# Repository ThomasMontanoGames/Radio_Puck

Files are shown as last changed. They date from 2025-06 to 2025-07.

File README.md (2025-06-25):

# Radio_Puck
Small STM32 based ethernet connected radio puck capable of full duplex transmit and receive as well as dual RX or dual TX. Capable of rates up to 1 Mbps and completely configurable for many kinds of different modes. This radio puck has been primarily designed to be your rubber duck that transmits a known signal while prototyping a receiver.

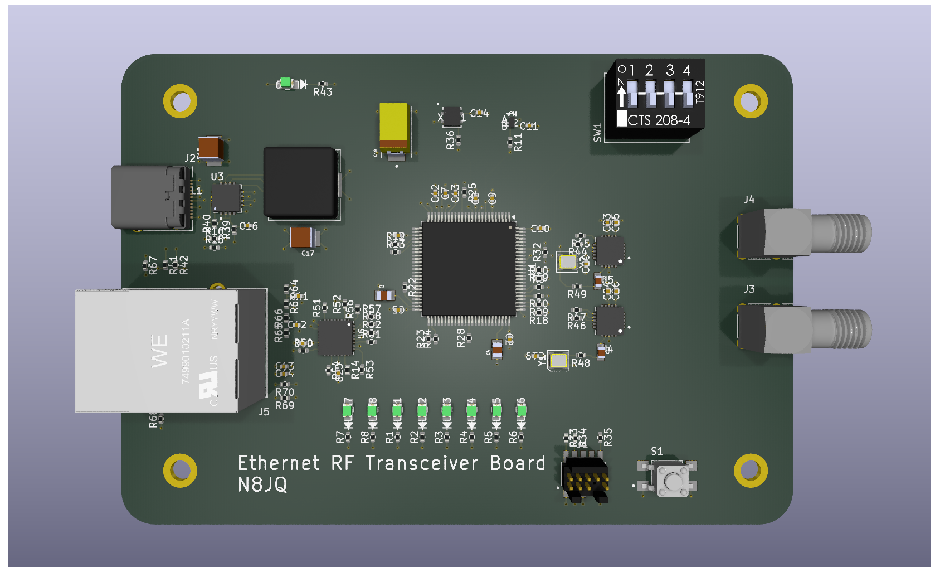
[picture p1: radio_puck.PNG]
Preliminary Layout


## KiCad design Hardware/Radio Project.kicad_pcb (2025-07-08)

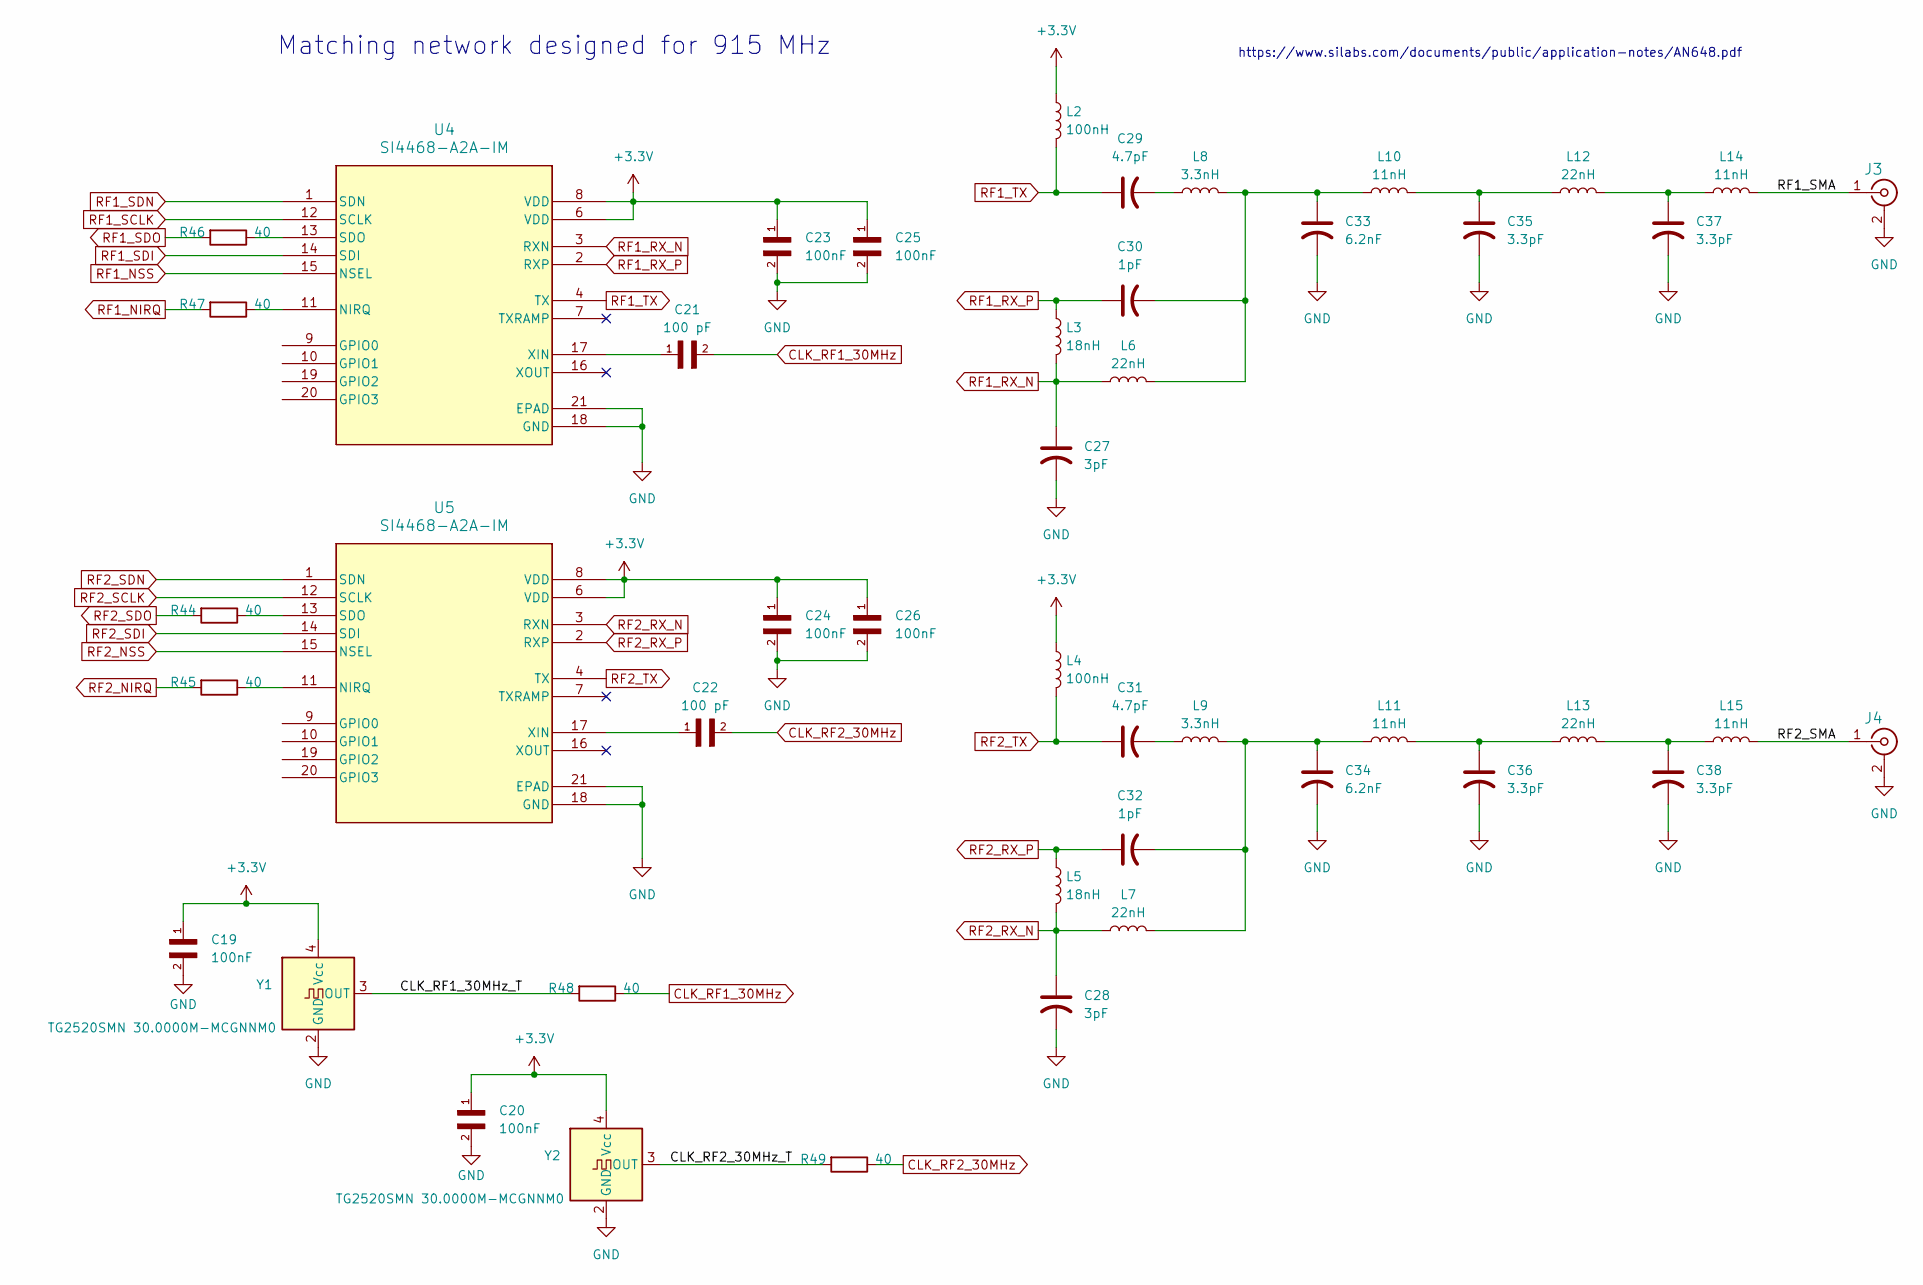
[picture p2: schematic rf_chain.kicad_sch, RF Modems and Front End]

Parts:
C19, C20, C23, C24, C25, C26: 100nF; CAPC10555_55N_KEM-L
C21, C22: 100 pF; CAPC1608X90N
C27, C28: 3pF; C_01005_0402Metric
C29, C31: 4.7pF; C_01005_0402Metric
C30, C32: 1pF; C_01005_0402Metric
C33, C34: 6.2nF; C_01005_0402Metric
C35, C36, C37, C38: 3.3pF; C_01005_0402Metric
J3, J4: 132225; CONN_132225_AMP
L2, L4: 100nH; L_0402_1005Metric
L3, L5: 18nH; L_0402_1005Metric
L6, L7, L12, L13: 22nH; L_0402_1005Metric
L8, L9: 3.3nH; L_0402_1005Metric
L10, L11, L14, L15: 11nH; L_0402_1005Metric
R44, R45, R46, R47, R48, R49: 40; R_0402_1005Metric
U4, U5: SI4468-A2A-IM; QFN50P400X400X90-21N
Y1, Y2: TG2520SMN 30.0000M-MCGNNM0; TG2520SMN

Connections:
+3.3V: C19.1, C20.1, C23.1, C24.1, C25.1, C26.1, L2.1, L4.1, U4.6 (VDD), U4.8 (VDD), U5.6 (VDD), U5.8 (VDD), Y1.4 (Vcc), Y2.4 (Vcc); also elsewhere on the board
/RF Chain/CLK_RF1_30MHz_T: R48.2, Y1.3 (OUT)
/RF Chain/CLK_RF2_30MHz_T: R49.2, Y2.3 (OUT)
/RF Chain/RF1_SMA: J3.1, L14.2
/RF Chain/RF2_SMA: J4.1, L15.2
CLK_RF1_30MHz: C21.2, R48.1
CLK_RF2_30MHz: C22.2, R49.1
GND: C19.2, C20.2, C23.2, C24.2, C25.2, C26.2, C27.2, C28.2, C33.2, C34.2, C35.2, C36.2, C37.2, C38.2, J3.2, J4.2, U4.18 (GND), U4.21 (EPAD), U5.18 (GND), U5.21 (EPAD), Y1.2 (GND), Y2.2 (GND); also elsewhere on the board
unnamed: C29.2, L8.1
unnamed: C30.2, C33.1, L6.2, L8.2, L10.1
unnamed: C31.2, L9.1
unnamed: C32.2, C34.1, L7.2, L9.2, L11.1
unnamed: C35.1, L10.2, L12.1
unnamed: C36.1, L11.2, L13.1
unnamed: C37.1, L12.2, L14.1
unnamed: C38.1, L13.2, L15.1
unnamed: R47.1, U4.11 (NIRQ)
unnamed: R46.1, U4.13 (SDO)
unnamed: C21.1, U4.17 (XIN)
unnamed: R45.1, U5.11 (NIRQ)
unnamed: R44.1, U5.13 (SDO)
unnamed: C22.1, U5.17 (XIN)
RF1_NIRQ: R47.2; also elsewhere on the board
RF1_NSS: U4.15 (NSEL); also elsewhere on the board
RF1_RX_N: C27.1, L3.2, L6.1, U4.3 (RXN)
RF1_RX_P: C30.1, L3.1, U4.2 (RXP)
RF1_SCLK: U4.12 (SCLK); also elsewhere on the board
RF1_SDI: U4.14 (SDI); also elsewhere on the board
RF1_SDN: U4.1 (SDN); also elsewhere on the board
RF1_SDO: R46.2; also elsewhere on the board
RF1_TX: C29.1, L2.2, U4.4 (TX)
RF2_NIRQ: R45.2; also elsewhere on the board
RF2_NSS: U5.15 (NSEL); also elsewhere on the board
RF2_RX_N: C28.1, L5.2, L7.1, U5.3 (RXN)
RF2_RX_P: C32.1, L5.1, U5.2 (RXP)
RF2_SCLK: U5.12 (SCLK); also elsewhere on the board
RF2_SDI: U5.14 (SDI); also elsewhere on the board
RF2_SDN: U5.1 (SDN); also elsewhere on the board
RF2_SDO: R44.2; also elsewhere on the board
RF2_TX: C31.1, L4.2, U5.4 (TX)

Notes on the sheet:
https://www.silabs.com/documents/public/application-notes/AN648.pdf
Matching network designed for 915 MHz

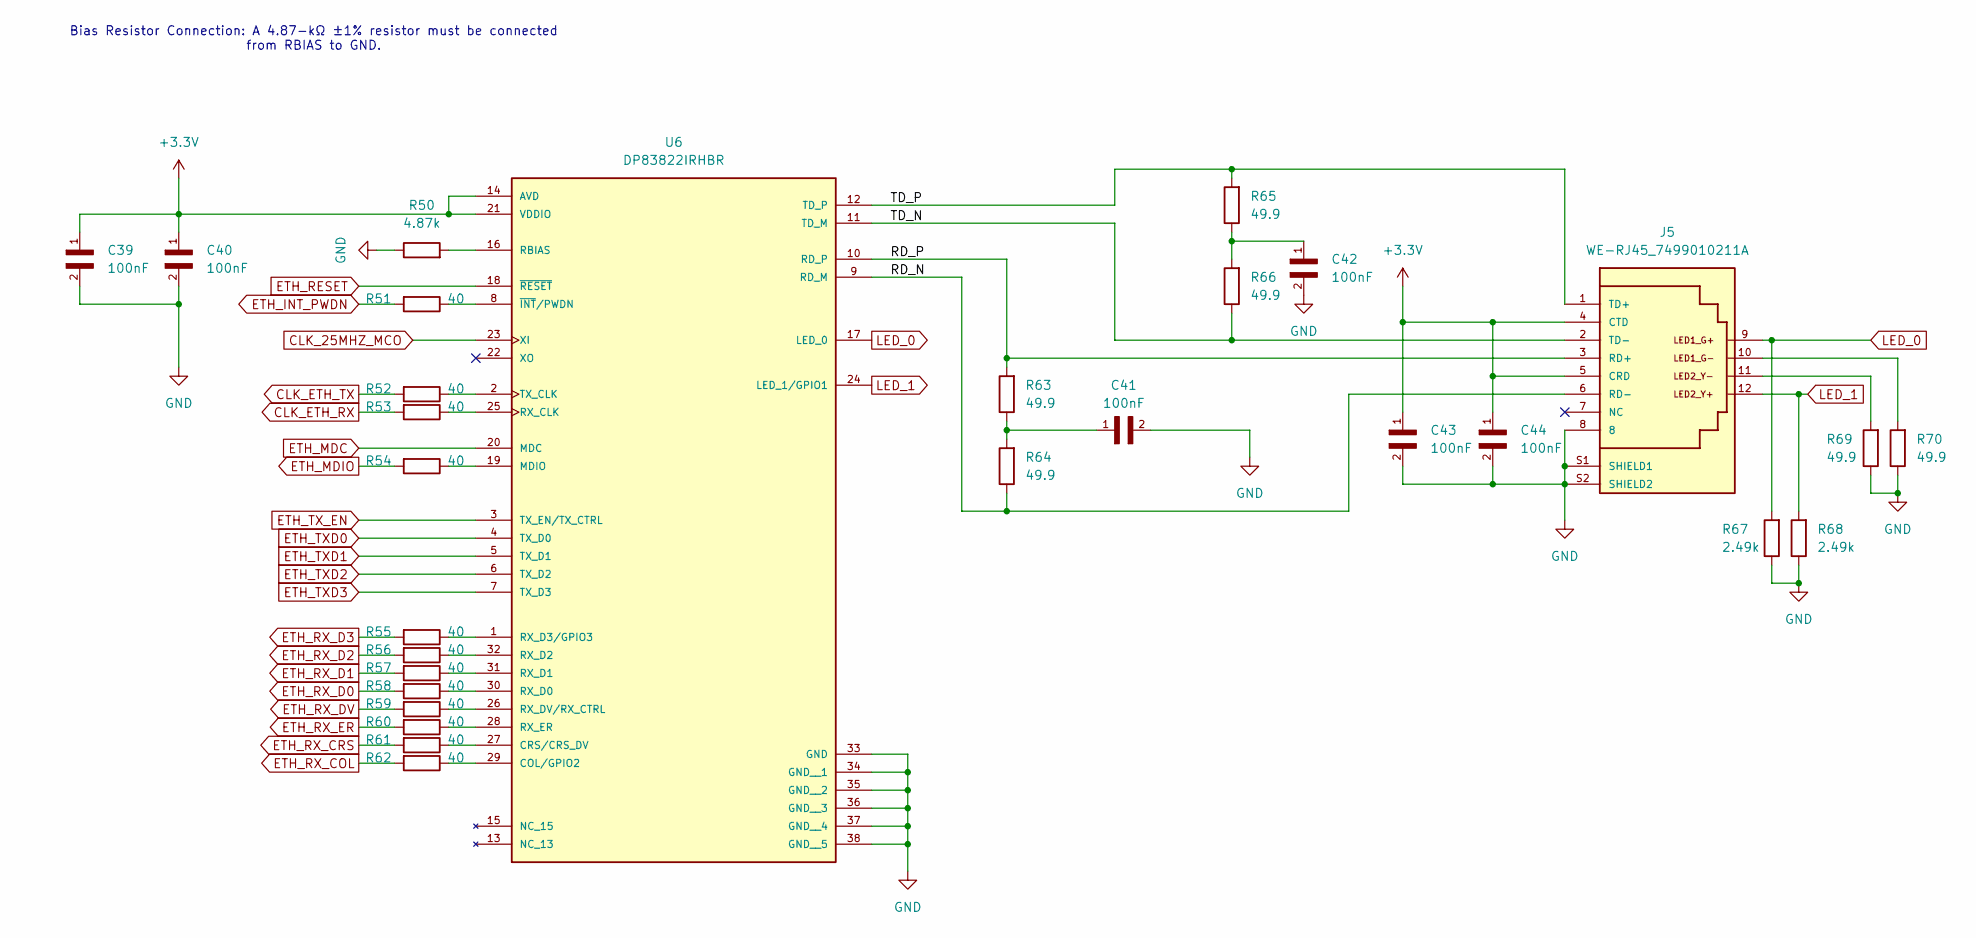
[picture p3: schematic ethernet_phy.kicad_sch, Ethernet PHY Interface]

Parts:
C39, C40, C41, C42, C43, C44: 100nF; CAPC10555_55N_KEM-L
J5: WE-RJ45_7499010211A; 7499010211A
R50: 4.87k; R_0402_1005Metric
R51, R52, R53, R54, R55, R56, R57, R58, R59, R60, R61, R62: 40; R_0402_1005Metric
R63, R64, R65, R66, R69, R70: 49.9; R_0402_1005Metric
R67, R68: 2.49k; R_0402_1005Metric
U6: DP83822IRHBR; IC_DP83822IRHBR; PARTREV 4223216/A 08/2016

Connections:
+3.3V: C39.1, C40.1, C43.1, C44.1, J5.4 (CTD), J5.5 (CRD), U6.14 (AVD), U6.21 (VDDIO); also elsewhere on the board
/Ethernet PHY/RD_N: J5.6 (RD-), R64.1, U6.9 (RD_M)
/Ethernet PHY/RD_P: J5.3 (RD+), R63.2, U6.10 (RD_P)
/Ethernet PHY/TD_N: J5.2 (TD-), R66.1, U6.11 (TD_M)
/Ethernet PHY/TD_P: J5.1 (TD+), R65.2, U6.12 (TD_P)
CLK_25MHZ_MCO: U6.23 (XI); also elsewhere on the board
CLK_ETH_RX: R53.2; also elsewhere on the board
CLK_ETH_TX: R52.2; also elsewhere on the board
ETH_INT_PWDN: R51.2; also elsewhere on the board
ETH_MDC: U6.20 (MDC); also elsewhere on the board
ETH_MDIO: R54.2; also elsewhere on the board
ETH_RESET: U6.18 (~RESET); also elsewhere on the board
ETH_RX_COL: R62.2; also elsewhere on the board
ETH_RX_CRS: R61.2; also elsewhere on the board
ETH_RX_D0: R58.2; also elsewhere on the board
ETH_RX_D1: R57.2; also elsewhere on the board
ETH_RX_D2: R56.2; also elsewhere on the board
ETH_RX_D3: R55.2; also elsewhere on the board
ETH_RX_DV: R59.2; also elsewhere on the board
ETH_RX_ER: R60.2; also elsewhere on the board
ETH_TXD0: U6.4 (TX_D0); also elsewhere on the board
ETH_TXD1: U6.5 (TX_D1); also elsewhere on the board
ETH_TXD2: U6.6 (TX_D2); also elsewhere on the board
ETH_TXD3: U6.7 (TX_D3); also elsewhere on the board
ETH_TX_EN: U6.3 (TX_EN/TX_CTRL); also elsewhere on the board
GND: C39.2, C40.2, C41.2, C42.2, C43.2, C44.2, J5.8, J5.S1 (SHIELD1), J5.S2 (SHIELD2), R50.1, R67.1, R68.1, R69.1, R70.1, U6.33 (GND), U6.34 (GND__1), U6.35 (GND__2), U6.36 (GND__3), U6.37 (GND__4), U6.38 (GND__5); also elsewhere on the board
LED_0: J5.9, R67.2, U6.17 (LED_0)
LED_1: J5.12, R68.2, U6.24 (LED_1/GPIO1)
unnamed: C41.1, R63.1, R64.2
unnamed: C42.1, R65.1, R66.2
unnamed: J5.10, R70.2
unnamed: J5.11, R69.2
unnamed: R62.1, U6.29 (COL/GPIO2)
unnamed: R61.1, U6.27 (CRS/CRS_DV)
unnamed: R54.1, U6.19 (MDIO)
unnamed: R50.2, U6.16 (RBIAS)
unnamed: R53.1, U6.25 (RX_CLK)
unnamed: R58.1, U6.30 (RX_D0)
unnamed: R57.1, U6.31 (RX_D1)
unnamed: R56.1, U6.32 (RX_D2)
unnamed: R55.1, U6.1 (RX_D3/GPIO3)
unnamed: R59.1, U6.26 (RX_DV/RX_CTRL)
unnamed: R60.1, U6.28 (RX_ER)
unnamed: R52.1, U6.2 (TX_CLK)
unnamed: R51.1, U6.8 (~INT/PWDN)

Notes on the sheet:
Bias Resistor Connection: A 4.87-kΩ ±1% resistor must be connected from RBIAS to GND.

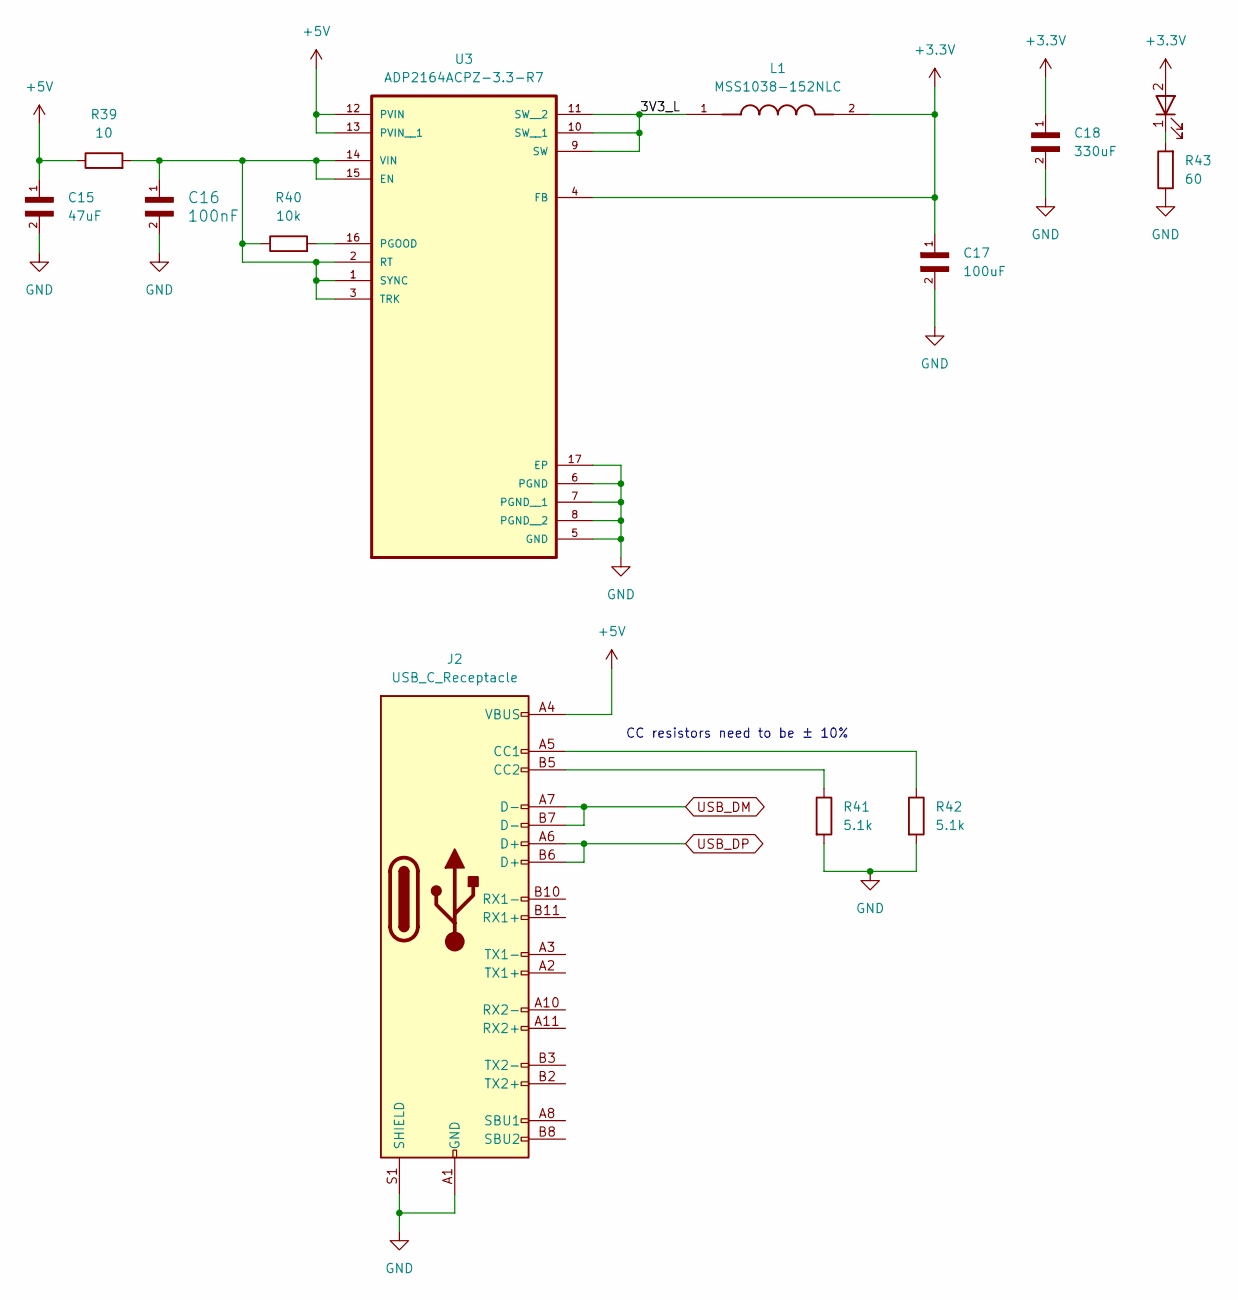
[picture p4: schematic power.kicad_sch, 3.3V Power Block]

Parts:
C15: 47uF; CAP_C3225X5R0J476M250AA; PARTREV 8/10/2022
C16: 100nF; CAPC10555_55N_KEM-L
C17: 100uF; CAP_C3225X5R0J107M250AB; PARTREV 8/10/2022
C18: 330uF; CAPPM7343X310N
J2: USB_C_Receptacle; USB_C_Receptacle_Amphenol_12401548E4-2A
L1: MSS1038-152NLC; L_Coilcraft_MSS1038-XXX; PARTREV 09/27/22
LED9: CMD17-21VGD/TR8; LED0805N_CML-M
R39: 10; R_0402_1005Metric
R40: 10k; R_0402_1005Metric
R41, R42: 5.1k; R_0402_1005Metric
R43: 60; R_0402_1005Metric
U3: ADP2164ACPZ-3.3-R7; QFN65P400X400X80-17N

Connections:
+3.3V: C17.1, C18.1, L1.2, LED9.2, U3.4 (FB); also elsewhere on the board
+5V: C15.1, J2.A4 (VBUS), J2.A9 (VBUS), J2.B4 (VBUS), J2.B9 (VBUS), R39.1, U3.12 (PVIN), U3.13 (PVIN__1)
/3V3 Power/3V3_L: L1.1, U3.9 (SW), U3.10 (SW__1), U3.11 (SW__2)
GND: C15.2, C16.2, C17.2, C18.2, J2.A1 (GND), J2.A12 (GND), J2.B1 (GND), J2.B12 (GND), J2.S1 (SHIELD), R41.2, R42.2, R43.1, U3.5 (GND), U3.6 (PGND), U3.7 (PGND__1), U3.8 (PGND__2), U3.17 (EP); also elsewhere on the board
unnamed: J2.A5 (CC1), R42.1
unnamed: J2.B5 (CC2), R41.1
unnamed: LED9.1, R43.2
unnamed: C16.1, R39.2, R40.1, U3.1 (SYNC), U3.2 (RT), U3.3 (TRK), U3.14 (VIN), U3.15 (EN)
unnamed: R40.2, U3.16 (PGOOD)
USB_DM: J2.A7 (D-), J2.B7 (D-); also elsewhere on the board
USB_DP: J2.A6 (D+), J2.B6 (D+); also elsewhere on the board

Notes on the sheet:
CC resistors need to be ± 10%

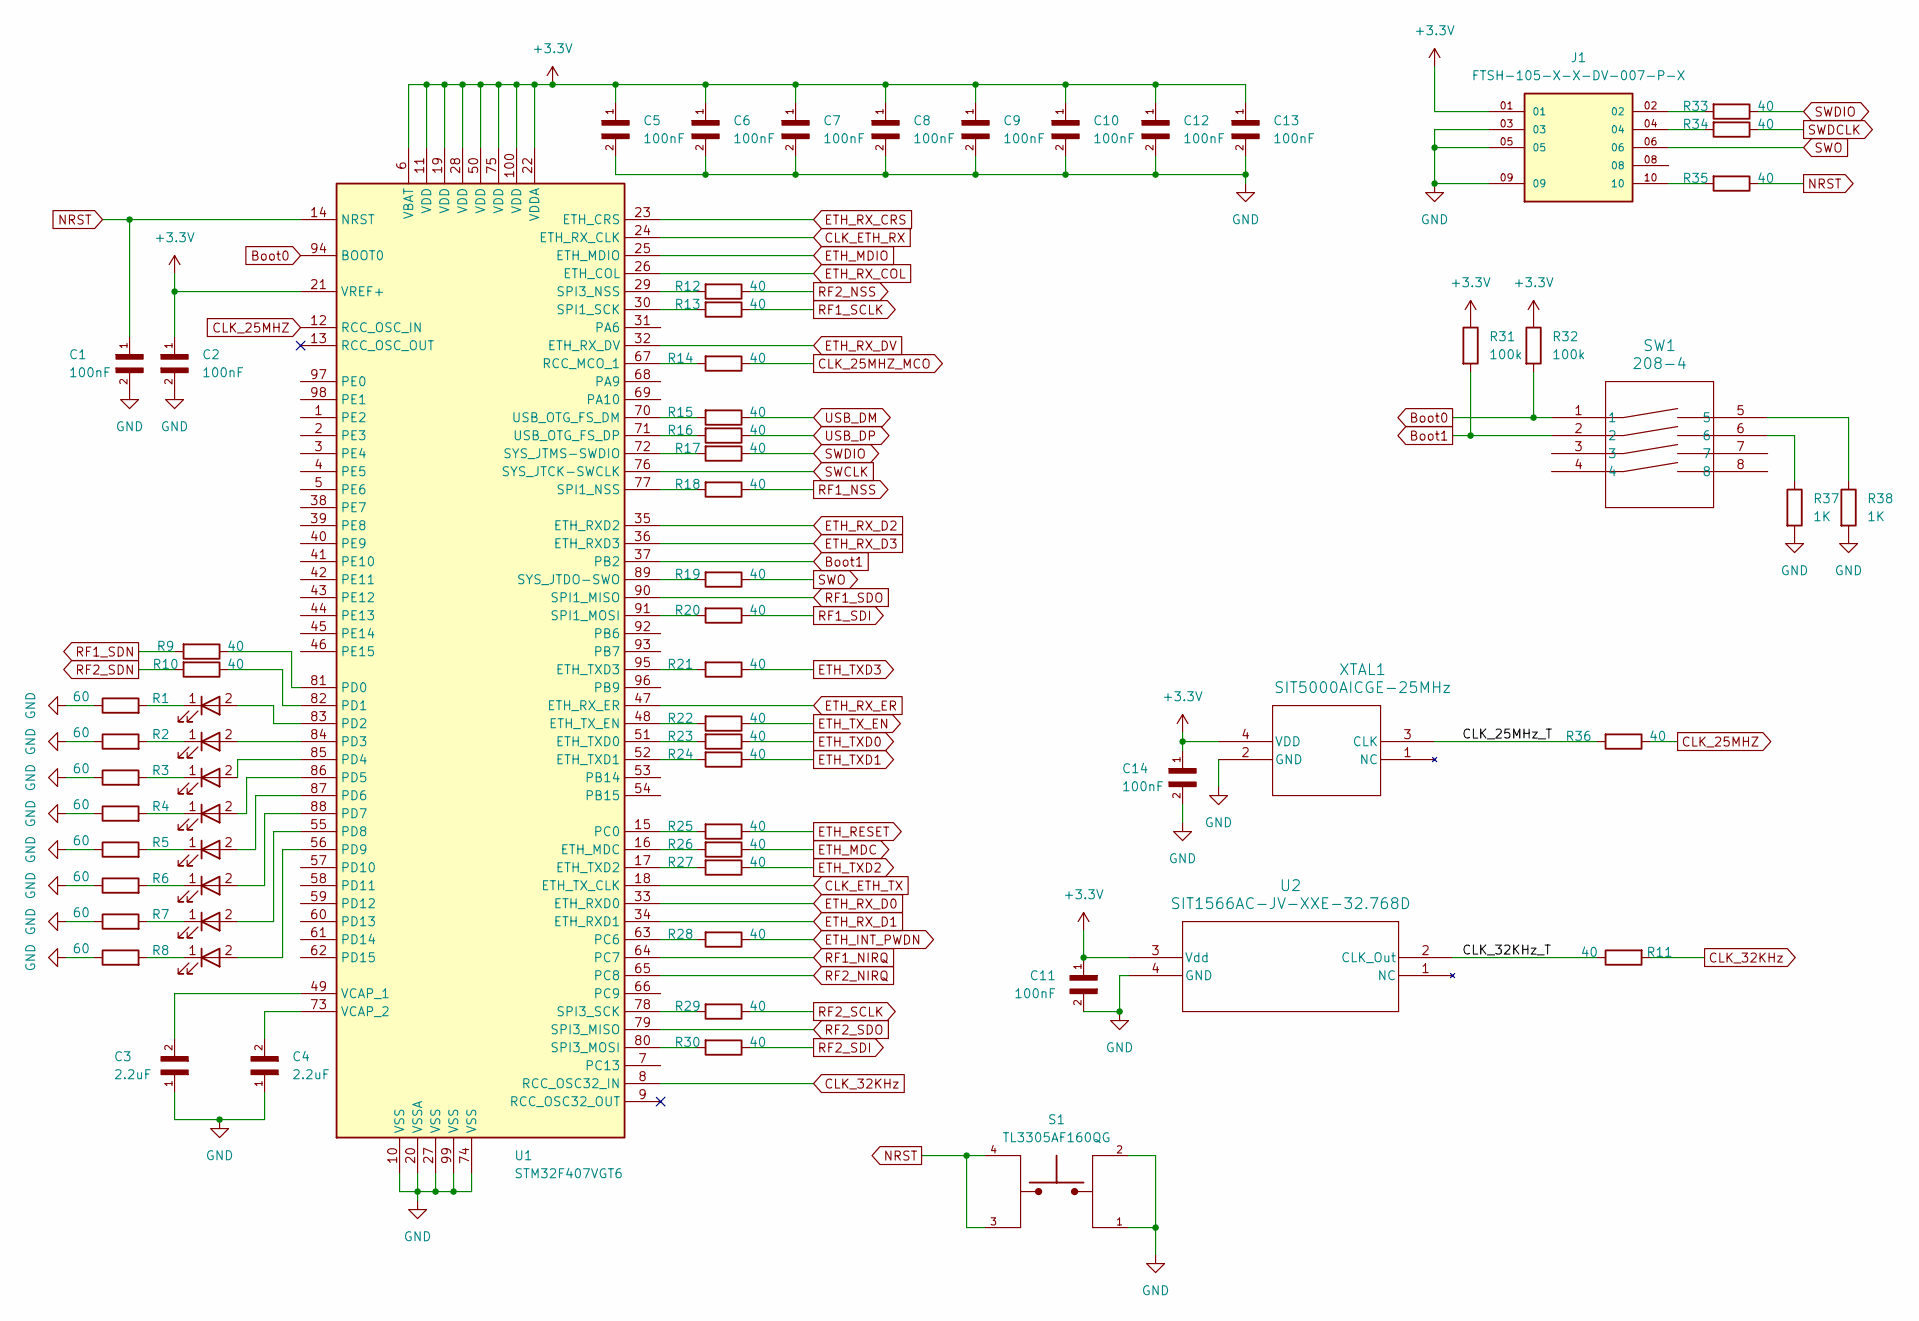
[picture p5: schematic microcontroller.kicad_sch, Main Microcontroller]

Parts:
C1, C2, C5, C6, C7, C8, C9, C10, C11, C12, C13, C14: 100nF; CAPC10555_55N_KEM-L
C3, C4: 2.2uF; CAPC2012X140N
J1: FTSH-105-X-X-DV-007-P-X; SAMTEC_FTSH-105-X-X-DV-007-P-X; PARTREV H
LED1, LED2, LED3, LED4, LED5, LED6, LED7, LED8: CMD17-21VGD/TR8; LED0805N_CML-M
R1, R2, R3, R4, R5, R6, R7, R8: 60; R_0402_1005Metric
R9, R10, R11, R12, R13, R14, R15, R16, R17, R18, R19, R20, R21, R22, R23, R24, R25, R26, R27, R28, R29, R30, R33, R34, R35, R36: 40; R_0402_1005Metric
R31, R32: 100k; R_0402_1005Metric
R37, R38: 1K; R_0402_1005Metric
S1: TL3305AF160QG; SW_TL3305AF160QG; PARTREV C
SW1: 208-4; DIP8_208-4_CTS
U1: STM32F407VGT6; LQFP-100_14x14mm_P0.5mm
U2: SIT1566AC-JV-XXE-32.768D; BGA_E-32.768D_SIT
XTAL1: SIT5000AICGE-25MHz; SIT5000_2.7x2.4_SIT-M

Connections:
+3.3V: C2.1, C5.1, C6.1, C7.1, C8.1, C9.1, C10.1, C11.1, C12.1, C13.1, C14.1, J1.01, R31.1, R32.1, U1.6 (VBAT), U1.11 (VDD), U1.19 (VDD), U1.21 (VREF+), U1.22 (VDDA), U1.28 (VDD), U1.50 (VDD), U1.75 (VDD), U1.100 (VDD), U2.3 (Vdd), XTAL1.4 (VDD); also elsewhere on the board
/Microcontroller/CLK_25MHz_T: R36.2, XTAL1.3 (CLK)
/Microcontroller/CLK_32KHz_T: R11.1, U2.2 (CLK_Out)
Boot0: R32.2, SW1.1, U1.94 (BOOT0)
Boot1: R31.2, SW1.2, U1.37 (PB2)
CLK_25MHZ: R36.1, U1.12 (RCC_OSC_IN)
CLK_25MHZ_MCO: R14.1; also elsewhere on the board
CLK_32KHz: R11.2, U1.8 (RCC_OSC32_IN)
CLK_ETH_RX: U1.24 (ETH_RX_CLK); also elsewhere on the board
CLK_ETH_TX: U1.18 (ETH_TX_CLK); also elsewhere on the board
ETH_INT_PWDN: R28.1; also elsewhere on the board
ETH_MDC: R26.1; also elsewhere on the board
ETH_MDIO: U1.25 (ETH_MDIO); also elsewhere on the board
ETH_RESET: R25.1; also elsewhere on the board
ETH_RX_COL: U1.26 (ETH_COL); also elsewhere on the board
ETH_RX_CRS: U1.23 (ETH_CRS); also elsewhere on the board
ETH_RX_D0: U1.33 (ETH_RXD0); also elsewhere on the board
ETH_RX_D1: U1.34 (ETH_RXD1); also elsewhere on the board
ETH_RX_D2: U1.35 (ETH_RXD2); also elsewhere on the board
ETH_RX_D3: U1.36 (ETH_RXD3); also elsewhere on the board
ETH_RX_DV: U1.32 (ETH_RX_DV); also elsewhere on the board
ETH_RX_ER: U1.47 (ETH_RX_ER); also elsewhere on the board
ETH_TXD0: R23.1; also elsewhere on the board
ETH_TXD1: R24.1; also elsewhere on the board
ETH_TXD2: R27.1; also elsewhere on the board
ETH_TXD3: R21.1; also elsewhere on the board
ETH_TX_EN: R22.1; also elsewhere on the board
GND: C1.2, C2.2, C3.1, C4.1, C5.2, C6.2, C7.2, C8.2, C9.2, C10.2, C11.2, C12.2, C13.2, C14.2, J1.03, J1.05, J1.09, R1.1, R2.1, R3.1, R4.1, R5.1, R6.1, R7.1, R8.1, R37.2, R38.2, S1.1, S1.2, U1.10 (VSS), U1.20 (VSSA), U1.27 (VSS), U1.74 (VSS), U1.99 (VSS), U2.4 (GND), XTAL1.2 (GND); also elsewhere on the board
NRST: C1.1, R35.1, S1.3, S1.4, U1.14 (NRST)
unnamed: J1.02, R33.2
unnamed: J1.04, R34.2
unnamed: J1.10, R35.2
unnamed: LED1.1, R1.2
unnamed: LED2.1, R2.2
unnamed: LED3.1, R3.2
unnamed: LED4.1, R4.2
unnamed: LED5.1, R5.2
unnamed: LED6.1, R6.2
unnamed: LED7.1, R7.2
unnamed: LED8.1, R8.2
unnamed: R37.1, SW1.6
unnamed: R38.1, SW1.5
unnamed: R12.2, U1.29 (SPI3_NSS)
unnamed: R13.2, U1.30 (SPI1_SCK)
unnamed: R14.2, U1.67 (RCC_MCO_1)
unnamed: R15.2, U1.70 (USB_OTG_FS_DM)
unnamed: R16.2, U1.71 (USB_OTG_FS_DP)
unnamed: R17.2, U1.72 (SYS_JTMS-SWDIO)
unnamed: R18.2, U1.77 (SPI1_NSS)
unnamed: R19.2, U1.89 (SYS_JTDO-SWO)
unnamed: R20.2, U1.91 (SPI1_MOSI)
unnamed: R21.2, U1.95 (ETH_TXD3)
unnamed: R22.2, U1.48 (ETH_TX_EN)
unnamed: R23.2, U1.51 (ETH_TXD0)
unnamed: R24.2, U1.52 (ETH_TXD1)
unnamed: R25.2, U1.15 (PC0)
unnamed: R26.2, U1.16 (ETH_MDC)
unnamed: R27.2, U1.17 (ETH_TXD2)
unnamed: R28.2, U1.63 (PC6)
unnamed: R29.2, U1.78 (SPI3_SCK)
unnamed: R30.2, U1.80 (SPI3_MOSI)
unnamed: R9.1, U1.81 (PD0)
unnamed: R10.1, U1.82 (PD1)
unnamed: LED1.2, U1.83 (PD2)
unnamed: LED2.2, U1.84 (PD3)
unnamed: LED3.2, U1.85 (PD4)
unnamed: LED4.2, U1.86 (PD5)
unnamed: LED5.2, U1.87 (PD6)
unnamed: LED6.2, U1.88 (PD7)
unnamed: LED7.2, U1.55 (PD8)
unnamed: LED8.2, U1.56 (PD9)
unnamed: C3.2, U1.49 (VCAP_1)
unnamed: C4.2, U1.73 (VCAP_2)
RF1_NIRQ: U1.64 (PC7); also elsewhere on the board
RF1_NSS: R18.1; also elsewhere on the board
RF1_SCLK: R13.1; also elsewhere on the board
RF1_SDI: R20.1; also elsewhere on the board
RF1_SDN: R9.2; also elsewhere on the board
RF1_SDO: U1.90 (SPI1_MISO); also elsewhere on the board
RF2_NIRQ: U1.65 (PC8); also elsewhere on the board
RF2_NSS: R12.1; also elsewhere on the board
RF2_SCLK: R29.1; also elsewhere on the board
RF2_SDI: R30.1; also elsewhere on the board
RF2_SDN: R10.2; also elsewhere on the board
RF2_SDO: U1.79 (SPI3_MISO); also elsewhere on the board
SWCLK: U1.76 (SYS_JTCK-SWCLK)
SWDCLK: R34.1
SWDIO: R17.1, R33.1
SWO: J1.06, R19.1
USB_DM: R15.1; also elsewhere on the board
USB_DP: R16.1; also elsewhere on the board

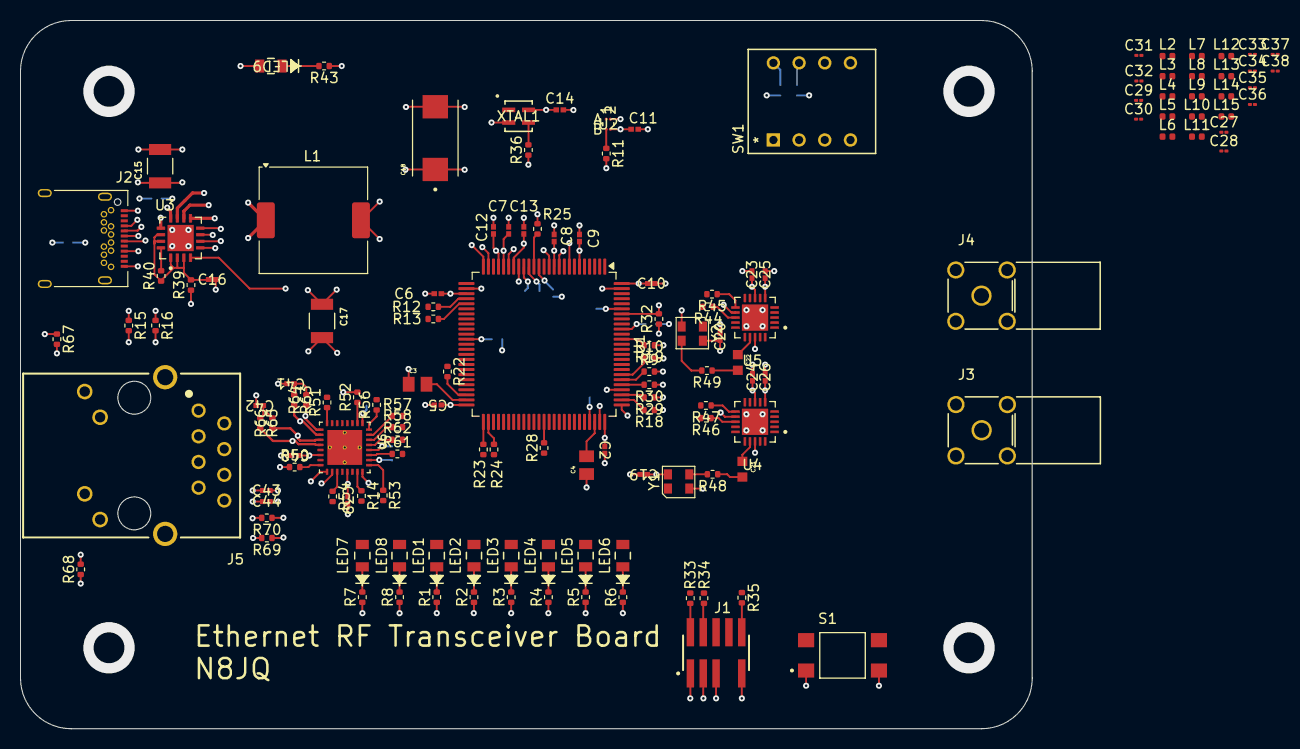
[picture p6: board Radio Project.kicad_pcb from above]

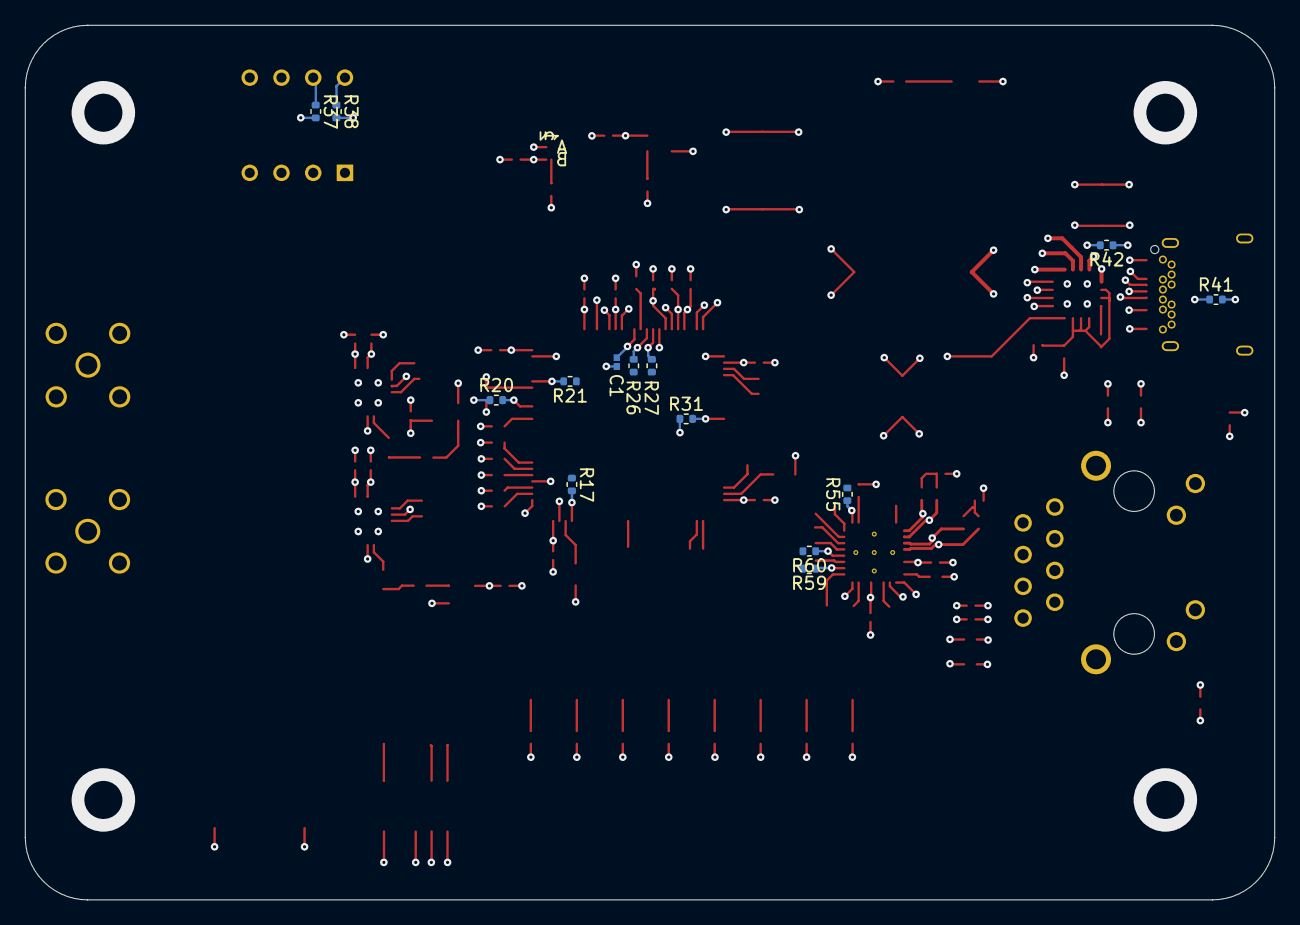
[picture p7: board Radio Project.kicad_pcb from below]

Board: 8 copper layers, 100.0 x 70.0 mm, 154 parts (14 on the bottom side), 145 nets.

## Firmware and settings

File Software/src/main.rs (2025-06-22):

#![no_std]
#![no_main]

// pick a panicking behavior
use panic_halt as _; // you can put a breakpoint on `rust_begin_unwind` to catch panics
// use panic_abort as _; // requires nightly
// use panic_itm as _; // logs messages over ITM; requires ITM support
// use panic_semihosting as _; // logs messages to the host stderr; requires a debugger

use cortex_m_rt::entry;

#[entry]
fn main() -> ! {
    loop {
        // your code goes here
    }
}

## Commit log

2025-06-22 Initial repo setup including firmware initialization and vscode config
    [Radio Project.kicad_pcb, Radio Project.kicad_sch]
2025-06-22 added SWD header and dip switches for boot modes
    [Radio Project.kicad_pcb, Radio Project.kicad_sch, power.kicad_sch]
2025-06-22 Added 3.3V power connections and a USB-C connector for +5V
    [Radio Project.kicad_pcb, Radio Project.kicad_sch, power.kicad_sch]
2025-06-23 added filtering caps, bulk decoupling caps, and power LED
    [Radio Project.kicad_pcb, Radio Project.kicad_sch, power.kicad_sch]
2025-06-23 added SMA connectors and external connections sheet
    [ExternalConnectors.kicad_sch, Radio Project.kicad_pcb, Radio Project.kicad_sch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]
2025-06-23 shutdown pin connection to RF chain
    [ExternalConnectors.kicad_sch, Radio Project.kicad_pcb, Radio Project.kicad_sch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]
2025-06-24 .gitignore update
    [ExternalConnectors.kicad_sch, Radio Project.kicad_pcb, Radio Project.kicad_sch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]
2025-06-24 Ethernet PHY and RJ45 connector
    [ExternalConnectors.kicad_sch, Radio Project.kicad_sch, ethernet_phy.kicad_sch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]
2025-06-24 Finished Ethernet connection between MAC and PHY
    [ExternalConnectors.kicad_sch, Radio Project.kicad_pcb, Radio Project.kicad_sch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]
2025-06-24 Added high power USB-C Connection (5V @ 3A)
    [ExternalConnectors.kicad_sch, Radio Project.kicad_pcb, Radio Project.kicad_sch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]
2025-06-25 git ignore update
    [ExternalConnectors.kicad_sch, Radio Project.kicad_pcb, Radio Project.kicad_sch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]
2025-06-25 Added oscillators, reset button, and finalized ETH connection
    [Radio Project.kicad_pcb, Radio Project.kicad_sch, ethernet_phy.kicad_sch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]
2025-06-25 changed to SI4468, added 30 MHz oscillators, and connected it to MCU
    [Radio Project.kicad_pcb, ethernet_phy.kicad_sch, microcontroller.kicad_sch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]
2025-06-25 fixed incorrect naming on RF clk and connected RF NIRQ lines
    [Radio Project.kicad_pcb, Radio Project.kicad_sch, microcontroller.kicad_sch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]
2025-06-26 gitignore update
    [Radio Project.kicad_pcb, Radio Project.kicad_sch, ethernet_phy.kicad_sch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]
2025-06-26 added item numbers to BOM settings
2025-06-26 added RF matching network and added all 16 layers to stackup
    [Radio Project.kicad_pcb, Radio Project.kicad_sch, ethernet_phy.kicad_sch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]
2025-06-26 connected USB 2.0 data pins
    [Radio Project.kicad_pcb, microcontroller.kicad_sch, power.kicad_sch]
2025-06-26 Added 5V plane
    [Radio Project.kicad_pcb]
2025-06-27 updated USB pin labels
    [microcontroller.kicad_sch]
2025-06-30 added stackup doc and reduced board to 10 layers
    [Radio Project.kicad_pcb, Radio Project.kicad_sch, ethernet_phy.kicad_sch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]
2025-06-30 initial 8 layer layout with power decoupling connections
    [Radio Project.kicad_pcb, Radio Project.kicad_sch, microcontroller.kicad_sch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]
2025-06-30 Placed termination resistors
    [ExternalConnectors.kicad_sch, Radio Project.kicad_pcb, Radio Project.kicad_sch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]
2025-06-30 ray tracing render of board
2025-07-07 fixed USB data lines and directory hierarchy
    [Radio Project.kicad_pcb, ethernet_phy.kicad_sch, microcontroller.kicad_sch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]
2025-07-08 diff pair routing for ethernet
    [Radio Project.kicad_pcb, power.kicad_sch]
